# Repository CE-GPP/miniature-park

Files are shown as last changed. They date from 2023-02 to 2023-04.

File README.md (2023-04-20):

# QEOP Data Dashboard Device

###### Dongyoung Lim, Jingqi Cheng, Patrick Whyte, Yining An
---
<p align="center">
Device
</p>

The QEOP Data Dashboard Device is a real-time, aesthetically pleasing data dashboard designed to provide users with comprehensive information about the Queen Elizabeth Olympic Park (QEOP) and its surrounding environment. The device combines the functionality of a data dashboard with the visual appeal of an objet d'art, making it accessible and engaging for general users.

<p align="center">
Controlling Device
</p>

## Features
- Real-time data visualisation
- Intuitive user experience with geographical context
- High-quality, visually appealing design
- Customisable map layers
- Interactive map with weather, network coverage, 3D buildings, and more

## Getting Started
1. Clone the repository.
```
git clone https://github.com/CE-GPP/miniature-park.git
```
2. Run the device control application.
```
cd device/controls
python main.py
```
3. Navigate to the project directory.
```
cd ../../
cd map/weatherleaflet
```
4. Install the required dependencies.
```
npm install
```
5. Run the backend application.
```
node app.js
```
6. Run the frontend application.
```
cd demo
npx live-server
```

## Tech Stack
### Map Application
- JavaScript
- Leaflet
- Node.js
- Express.js
- Socket.io
- MQTT.js

### Device Control
- Python
- Adafruit GFX Library
- Adafruit-ST7735-Library

### Device Components
- Raspberry Pi 4 Model B
- Elecrow RC070LCD Display with Touch Screen
- Adafruit 1.9" 320x170 Color IPS TFT Display
- EC11 Rotary Encoder Module

> Bill of Materials : https://github.com/CE-GPP/miniature-park/blob/main/report/src/Sketch_bom.png

## Project Structure
- `device/controls` : Contains code for the sub-display and the rotary encoder.
- `device/device model` : Contains 3d model of enclosure.
- `device/fabrication` : Contains drawings of the enclosure for fabrication.
- `device/map`: Contains 3d model of QEOP map for the 3d printing.
- `map/weatherleaflet` : Contains map application including the frontend and backend.

## Application architecture

<p align="center">
Application architecture
</p>

## Development procedures
- Design and development of a transparent 3D printed model in Blender.
- Creation of a wooden enclosure using laser cutting and wood stain to achieve a classic oak appearance.
- Integration of a 7-inch main display with HDMI support, a 1.9-inch sub-display with a custom UI for a dynamic data feed, and an EC11 rotary encoder for easy control.
- Utilisation of a Raspberry Pi 4 for computing and displaying data, allowing for quick software development using Python and web-based frameworks.

<p align="center">
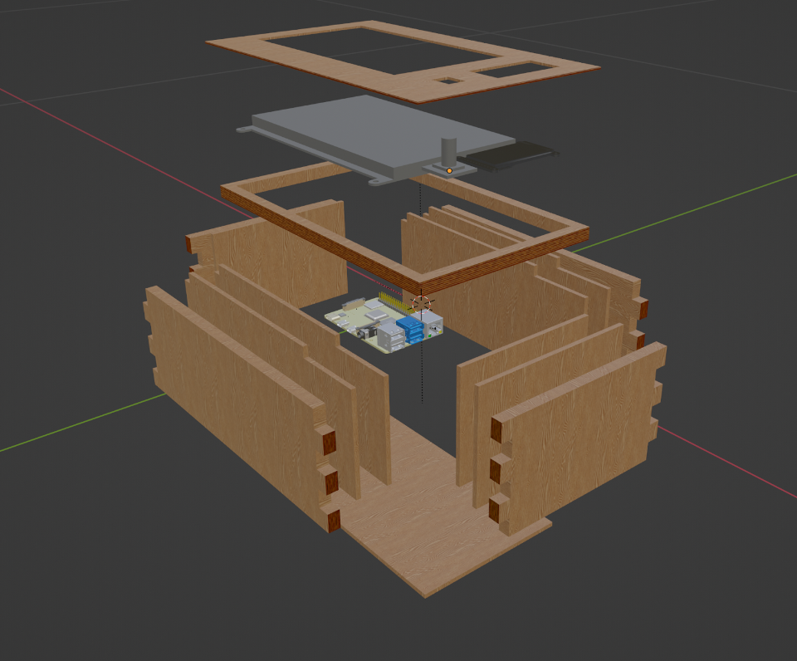
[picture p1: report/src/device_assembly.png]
Device Assembly

</p>

## Contributing
We welcome contributions from the community. If you'd like to contribute to the QEOP Data Dashboard Device, please follow these steps:

1. Fork the repository
2. Create a new branch with a descriptive name, e.g., feature/new-map-layer
3. Commit your changes to the new branch
4. Submit a pull request to the main repository

Please make sure your code follows the existing style guidelines and provide a detailed description of your changes in the pull request.

<p align="center">
Device
</p>

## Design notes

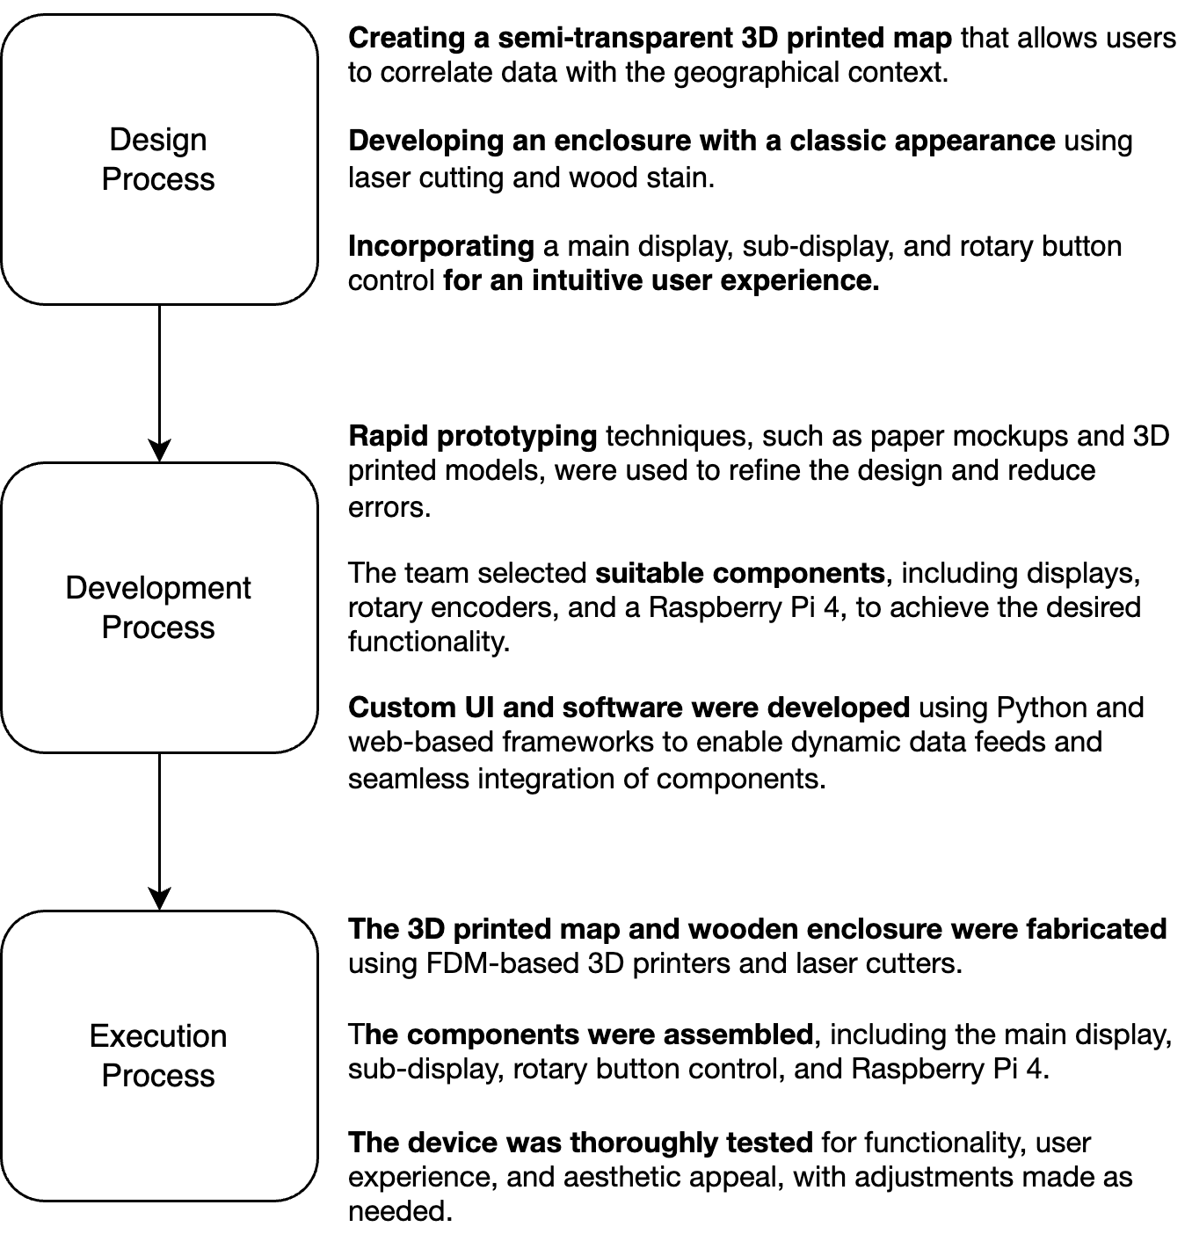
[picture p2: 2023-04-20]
report/src/Development Process.png

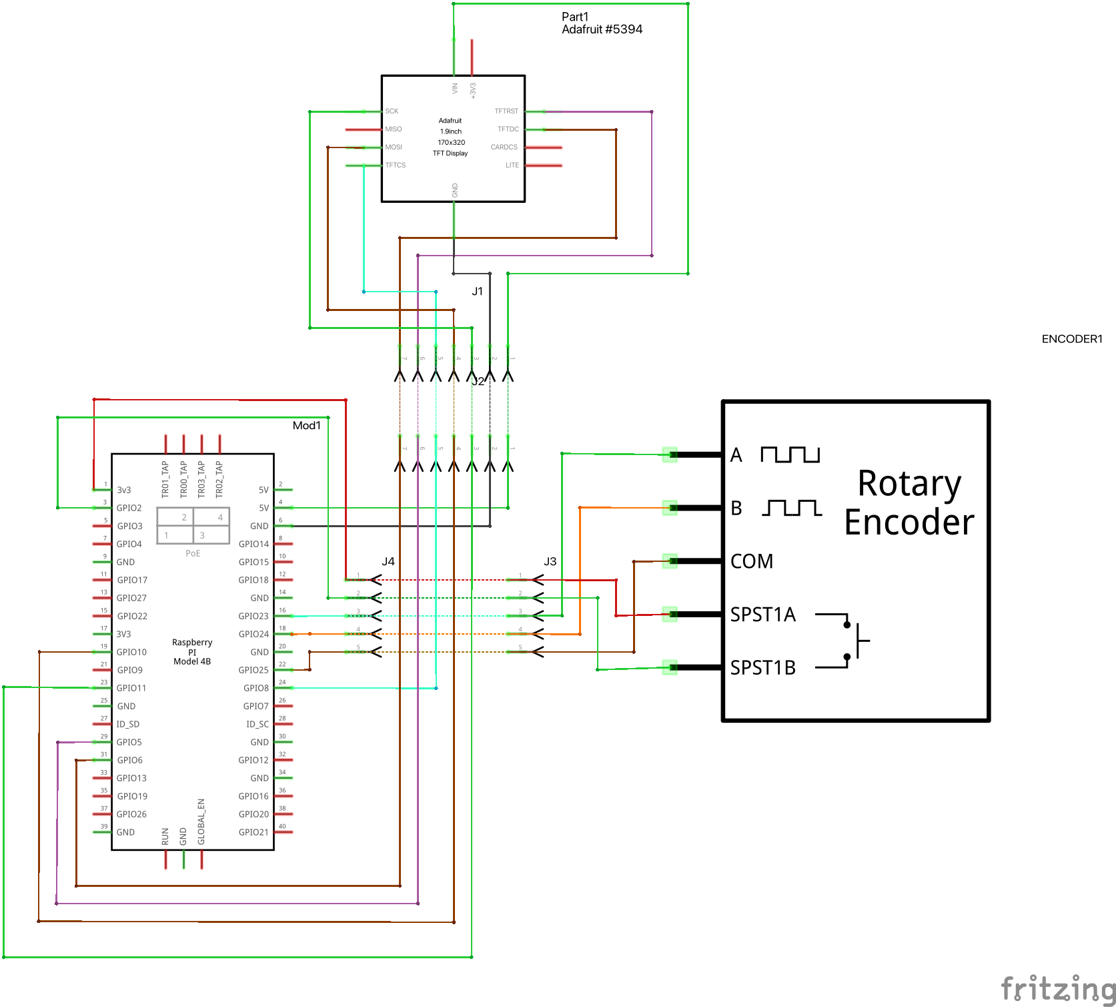
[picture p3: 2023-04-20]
report/src/Sketch_schem.png

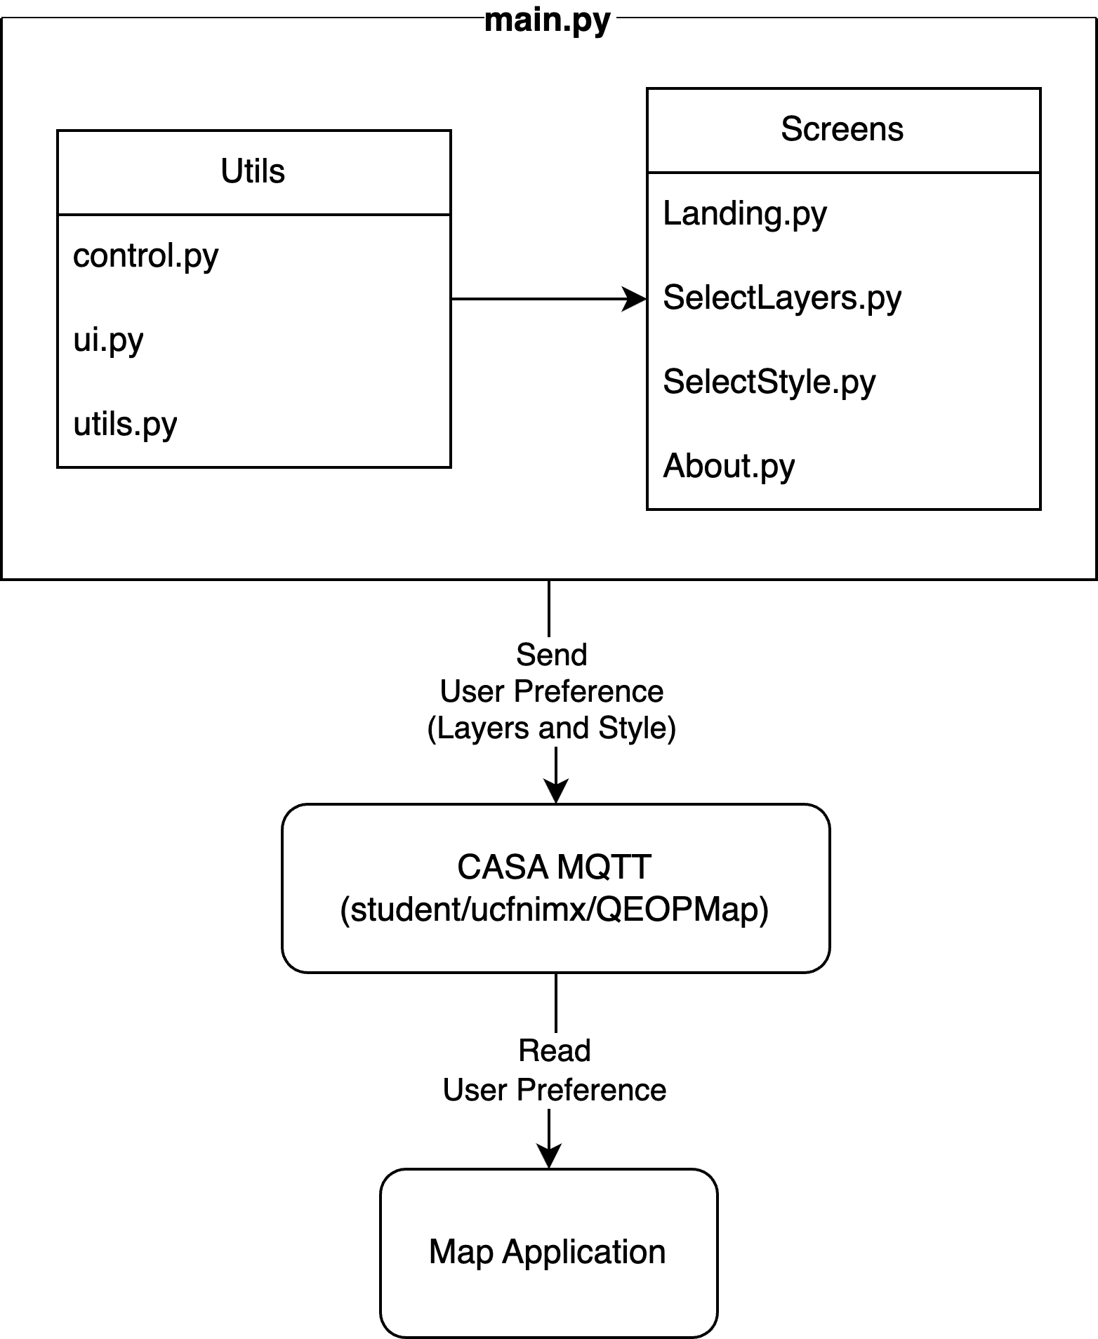
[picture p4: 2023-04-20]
report/src/UI.png

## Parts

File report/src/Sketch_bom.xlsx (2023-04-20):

Bill of Materials
Assembly List
Label | Part Type | Properties | Price | Link
ENCODER1 | EC11 Rotary Encoder Module | Module Size: 33.8 * 22.4 (mm) /1.3 * 1.1 (inches) | £3.00 | https://shop.pimoroni.com/products/ec11-rotary-encoder-module
J1 | Generic female header - 7 pins | package THT; pins 7; hole size 1.0mm,0.508mm; row single; pin spacing 0.1in (2.54mm); form ♀ (female) | £2.00 | https://shop.pimoroni.com/products/female-headers
J2 | Generic female header - 7 pins | package THT; pins 7; hole size 1.0mm,0.508mm; row single; pin spacing 0.1in (2.54mm); form ♀ (female)
J3 | Generic female header - 5 pins | package THT; pins 5; hole size 1.0mm,0.508mm; row single; pin spacing 0.1in (2.54mm); form ♀ (female)
J4 | Generic female header - 5 pins | package THT; pins 5; hole size 1.0mm,0.508mm; row single; pin spacing 0.1in (2.54mm); form ♀ (female)
Mod1 | Raspberry Pi 4B | processor Broadcom 2711, Quad-core Cortex-A72 64-bit SoC @ 1.5GHz; variant Raspberry Pi 4B | £62.40 | https://shop.pimoroni.com/products/raspberry-pi-4?variant=29157087445075
Part1 | Adafruit 1.9in 320x170 TFT | variant variant 1; part # Adafruit #5394 | £17.10 | https://shop.pimoroni.com/products/adafruit-1-9-320x170-color-ips-tft-display-st7789
 | Elecrow RC070LCD Display with Touch Screen | 7 Inch 1024*600 HDMI | £50.00 | https://www.amazon.co.uk/gp/product/B076J8ZWFF
 |  | Total | £134.50
Enclosure
Label | Part Name | Size | Price | Link
 | Plywood - 3mm | 600mm x 300mm | £4.00 | https://www.amazon.co.uk/Trustleaf-300x600mm-Plywood-Sheets-SECONDS/
 | Plywood - 8mm | 600mm x 300mm | £12.45 | https://www.amazon.co.uk/Birch-Plywood-making-furniture-300mm/
 | Furniture Clinic Wood Stain | 250 ml | £9.45 | https://www.amazon.co.uk/Furniture-Clinic-Stain-250ml-Mahogany/
 |  | Total | £25.90
 |  | Grand Total | £160.40

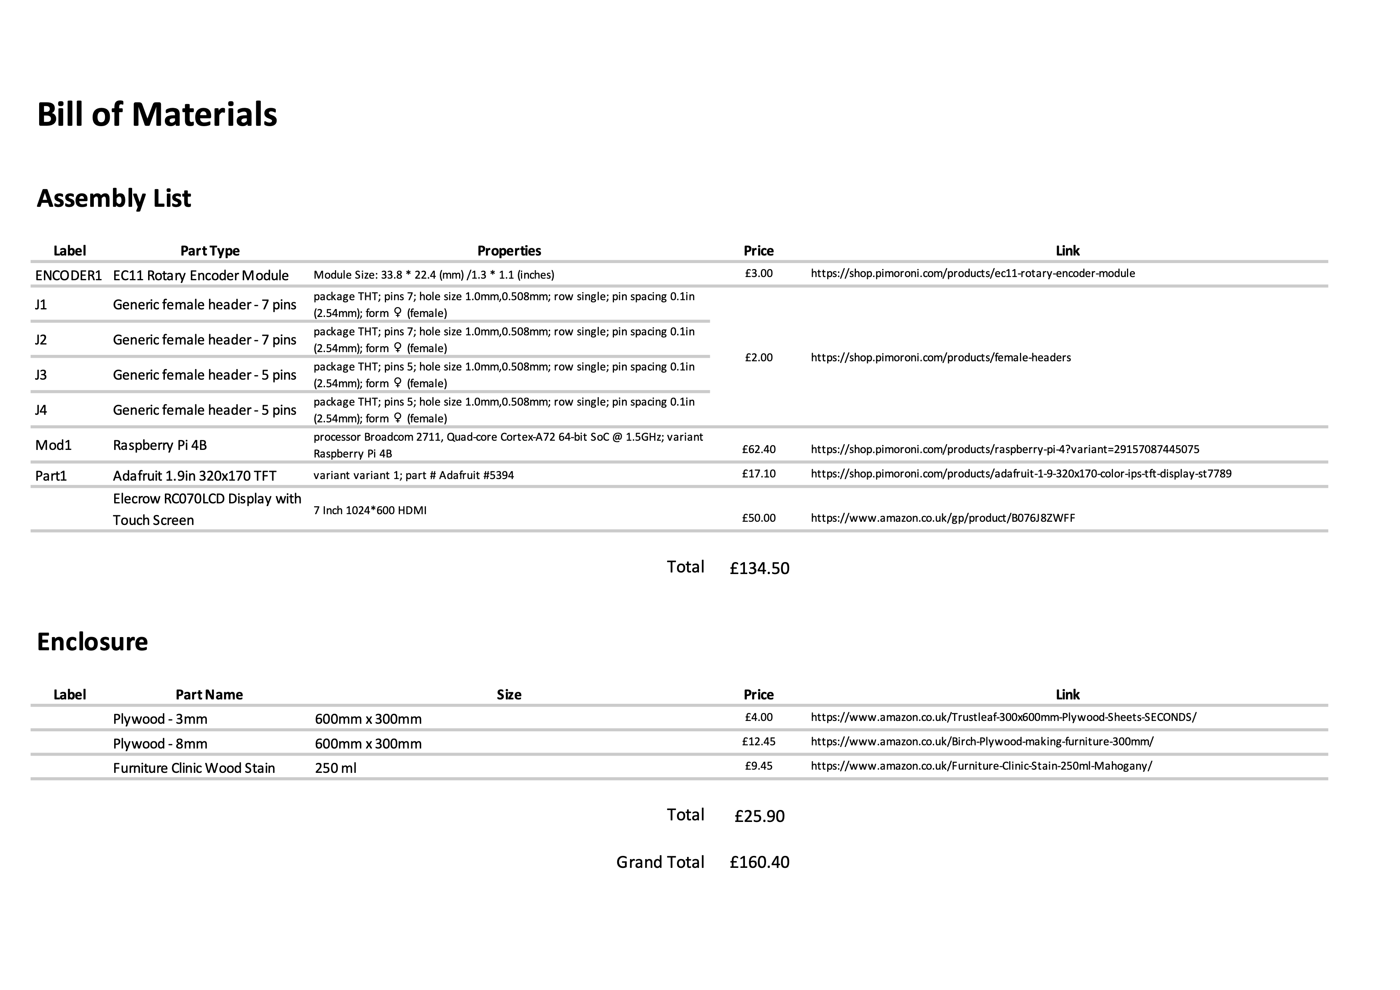
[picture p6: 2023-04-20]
report/src/Sketch_bom.png

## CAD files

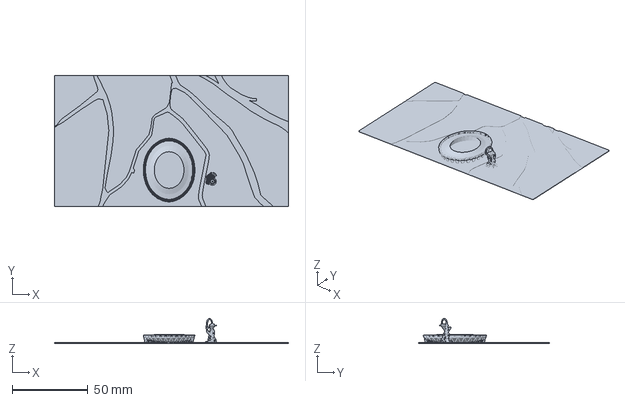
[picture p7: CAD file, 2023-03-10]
device/map/UMS5_QEOP_Scaled_test.3mf
154.0 x 86.0 x 16.7 mm

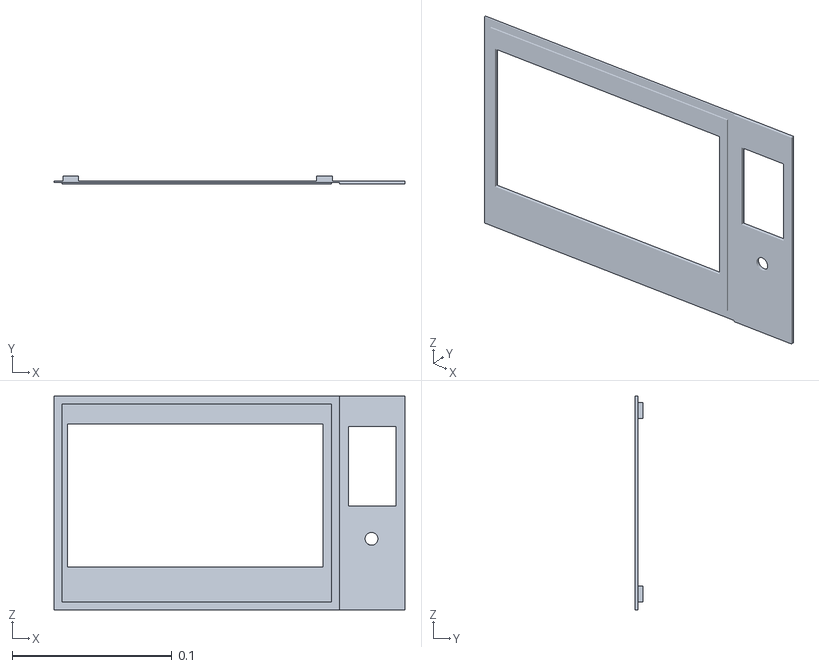
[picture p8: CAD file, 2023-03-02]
device/prototype models/holder2.stl
0.22 x 0.005 x 0.134

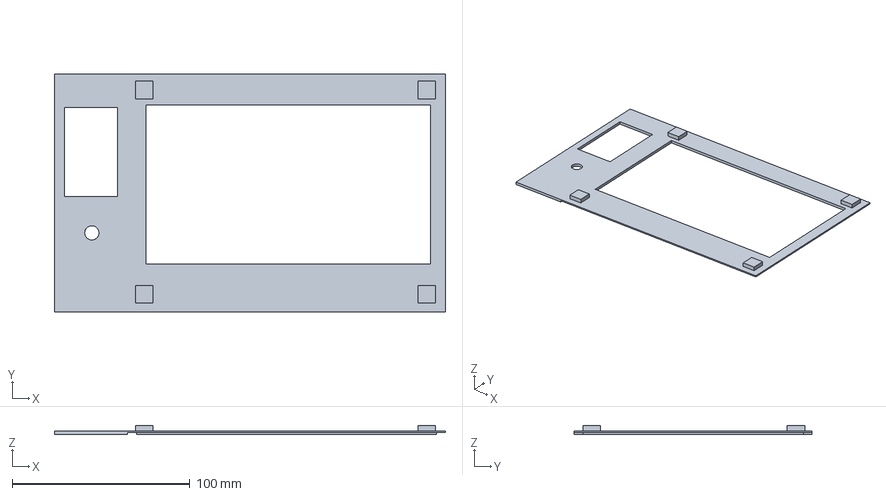
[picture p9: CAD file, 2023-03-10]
device/prototype models/prusa/holder2_v2.3mf
220.0 x 134.0 x 5.00 mm

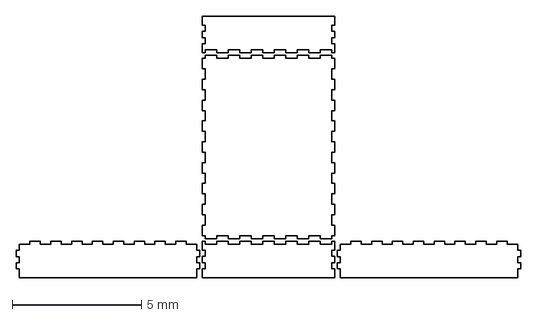
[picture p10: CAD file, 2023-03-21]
device/fabrication/cover_dxf.dxf
19.5 x 10.1 mm

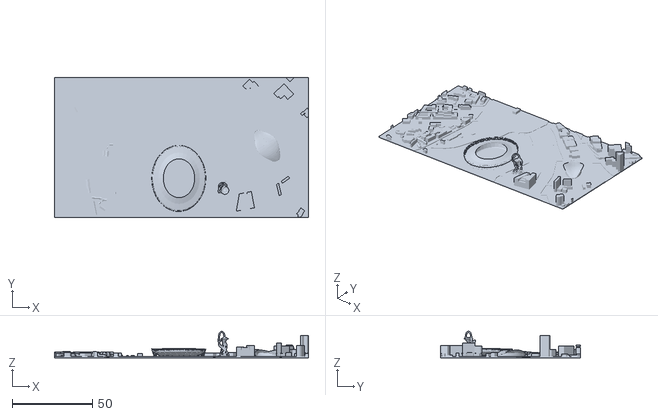
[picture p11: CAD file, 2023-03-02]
device/map/QEOP_v2.stl
158.0 x 87.0 x 16.7

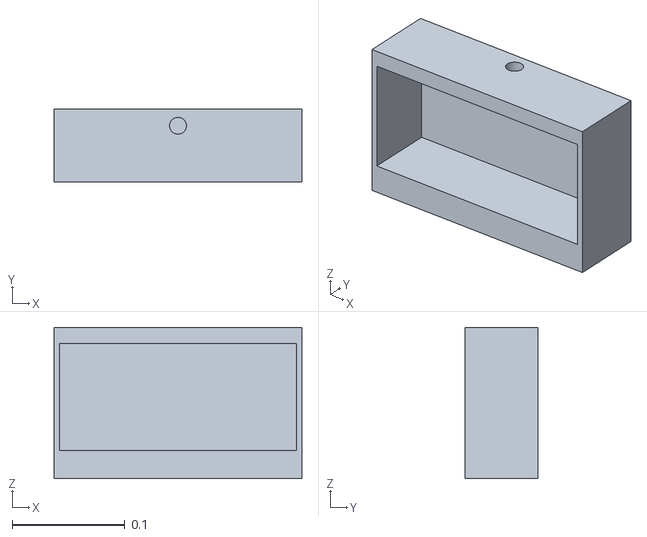
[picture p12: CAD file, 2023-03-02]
device/prototype models/container_V2.stl
0.22 x 0.065 x 0.134

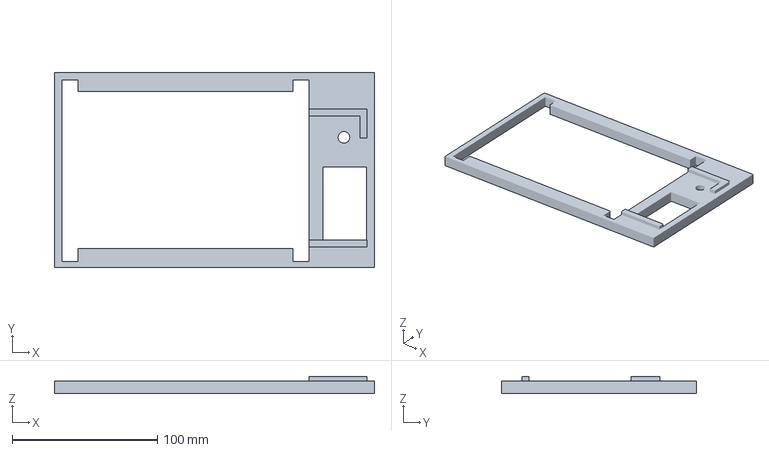
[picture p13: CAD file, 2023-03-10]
device/prototype models/prusa/holder1_v2.3mf
220.0 x 134.0 x 11.8 mm

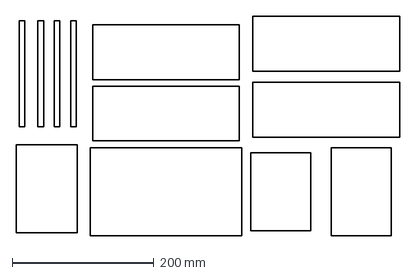
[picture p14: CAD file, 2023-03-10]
device/fabrication/3.5.dxf
540.5 x 309.3 mm

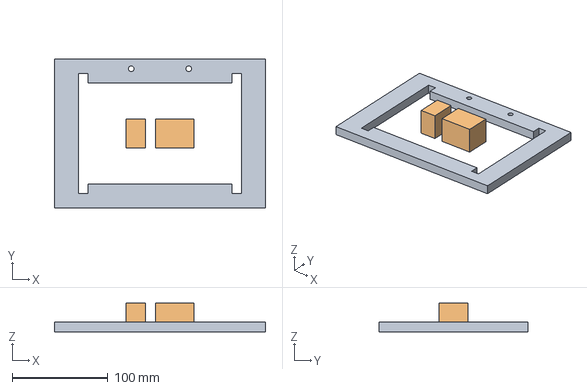
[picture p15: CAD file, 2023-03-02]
device/prototype models/prusa/support.3mf
220.0 x 155.0 x 30.0 mm
holder1.stl
support.stl

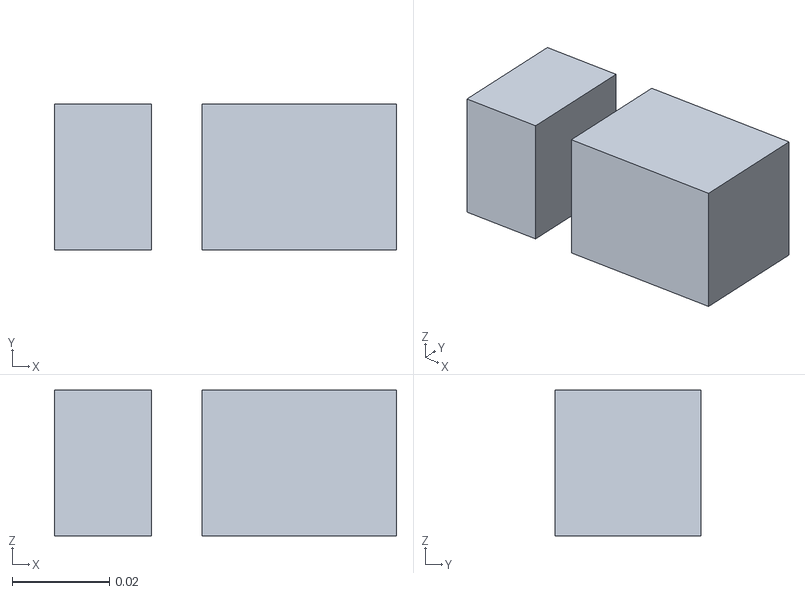
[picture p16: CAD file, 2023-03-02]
device/prototype models/support.stl
0.0704 x 0.03 x 0.03

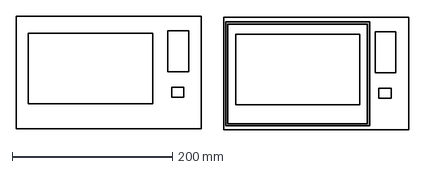
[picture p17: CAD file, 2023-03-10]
device/fabrication/1.5.dxf
489.9 x 142.2 mm

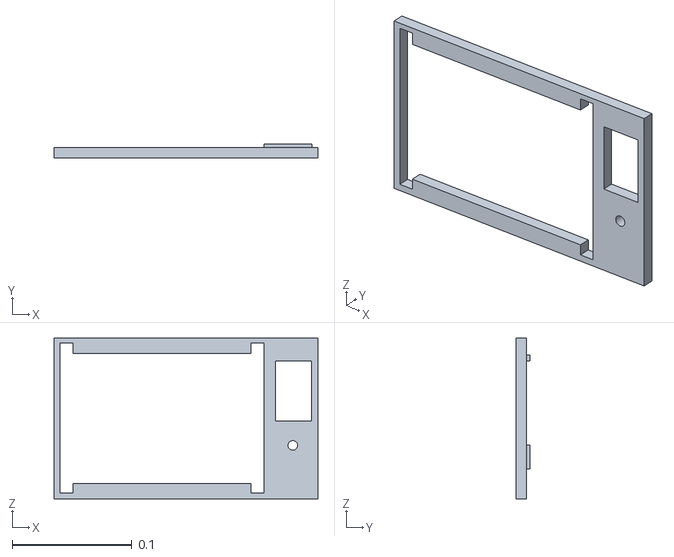
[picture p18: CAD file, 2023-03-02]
device/prototype models/holder1.stl
0.22 x 0.0118 x 0.134

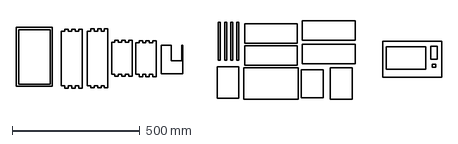
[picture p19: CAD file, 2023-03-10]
device/fabrication/production.dxf
1665.5 x 309.3 mm

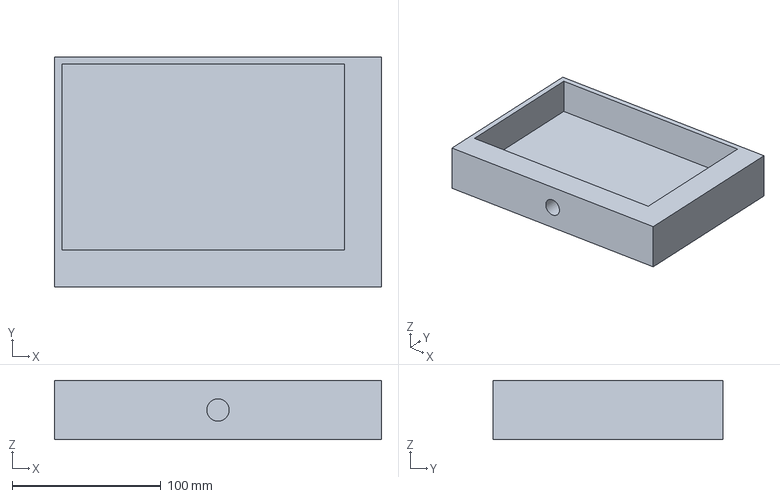
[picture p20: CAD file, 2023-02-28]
device/prototype models/prusa/container.3mf
220.0 x 155.0 x 40.0 mm

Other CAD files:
device/fabrication/cover.dwg
device/fabrication/8.5.dxf
device/prototype models/prusa/holder2.3mf
device/prototype models/container.stl
device/fabrication/1.5.dwg
device/fabrication/3.5.dwg
device/fabrication/8.5.dwg
device/fabrication/production.dwg
device/prototype models/3dPrintConfigModel.blend

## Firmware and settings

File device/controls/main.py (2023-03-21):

import sys
sys.path.append('/home/DYpi/QEOP/screens')
sys.path.append('/home/DYpi/QEOP/utils')
import board
import displayio
import utils as utils
import SelectLayers as SelectLayers
import SelectStyle as SelectStyle
import Landing as Landing
import About as About
from adafruit_st7789 import ST7789

spi = board.SPI()
tft_cs = board.D8
tft_rst = board.D5
tft_dc = board.D6

baseLayers = {'Satellite' : 'Satellite', 
              'GreyCanvas' : 'Grey'
              }
overLayers= {
    'Weather' : 'weather', 
    'Network':'heatmapLayer', 
    '3D':'osmb', 
    'Shadow':'shadeMap', 
    'Bycycle':'markerLayer',
    'Wind':"Wind"
    }

menu = ['Layers','Style','About']

# Release any resources currently in use for the displays
displayio.release_displays()
display_bus = displayio.FourWire(spi, command=tft_dc, chip_select=tft_cs, reset=tft_rst)
display = ST7789(display_bus, width=170, height=320, colstart=35, rotation=0, brightness = 1, backlight_pin = board.D13)


while True:
    landingPage = Landing.LandingScreen(display, displayio, menu)
    menuIndex = landingPage.runScreen()
    if menuIndex == 0:
        selectLayersScreen = SelectLayers.SelectLayers(display, displayio, overLayers)
        print(selectLayersScreen.runScreen())
    elif menuIndex == 1:
        selectStyleScreen = SelectStyle.SelectStyle(display, displayio, baseLayers)
        print(selectStyleScreen.runScreen())
    elif menuIndex == 2:
        aboutScreen = About.AboutScreen(display, displayio)
        aboutScreen.runScreen()
    else:
        print(menuIndex)
# selectLayersScreen = SelectLayers.SelectLayers(display, displayio, layers)
# print(selectLayersScreen.runScreen())

# display_bus.reset()

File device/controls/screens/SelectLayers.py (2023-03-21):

import sys
sys.path.append('/home/DYpi/QEOP/utils')
import time
import RPi.GPIO as GPIO
import json
import utils as utils
import ui as ui
import colors as colors

FOCUS = 0
SECRETE_ADDRESS = 'QEOP/secrete.txt'

encoderPinA = 23
encoderPinB = 24
buttonPin = 25

encoderValue = 0
previousValue = 0
lastEncoded = 0


def update_encoder(channel):
    global encoderValue, lastEncoded
    MSB = GPIO.input(encoderPinA)
    LSB = GPIO.input(encoderPinB)

    encoded = (MSB << 1) | LSB
    sum = (lastEncoded << 2) | encoded

    if sum == 0b1101 or sum == 0b0100 or sum == 0b0010 or sum == 0b1011:
        encoderValue += 1
    if sum == 0b1110 or sum == 0b0111 or sum == 0b0001 or sum == 0b1000:
        encoderValue -= 1

    lastEncoded = encoded

def moveFocus(direction, layers):
    global FOCUS
    itemNumber = len(layers)
    if direction == True:
        FOCUS = FOCUS + 1 if FOCUS + 1 < itemNumber else 0
    else:
        FOCUS = itemNumber - 1 if FOCUS - 1 < 0 else FOCUS - 1

def read_encoder_value(layers):
    global encoderValue, previousValue
    value = encoderValue // 4
    change = (value - previousValue)
    if change > 0:
        moveFocus(True, layers)
    elif change < 0:
        moveFocus(False, layers)
    previousValue = value
    return value

def is_button_push_down():
    debounce_time = 50  # set the debounce time in milliseconds
    if not GPIO.input(buttonPin):
        time.sleep(debounce_time/1000.0)  # wait for the debounce time
        if not GPIO.input(buttonPin):
            return True
    return False

class SelectLayers:
    def __init__(self, display, diaply_io, layers):
        self.display = display
        self.displayio = diaply_io
        self.menu = self.displayio.Group()
        self.layers = layers
        self.colour = colors.Colors()

        try:
            GPIO.setmode(GPIO.BCM)

            GPIO.setup(encoderPinA, GPIO.IN, pull_up_down=GPIO.PUD_UP)
            GPIO.setup(encoderPinB, GPIO.IN, pull_up_down=GPIO.PUD_UP)
            GPIO.setup(buttonPin, GPIO.IN, pull_up_down=GPIO.PUD_UP)

            GPIO.add_event_detect(encoderPinA, GPIO.BOTH, callback=update_encoder)
            GPIO.add_event_detect(encoderPinB, GPIO.BOTH, callback=update_encoder)
        except:
            GPIO.cleanup()
            print("Set Up Connection Failed.")

    def runScreen(self):
        global FOCUS
        layersDict = self.layers
        displayLayer = list(layersDict.keys())
        valueLayer = list(layersDict.values())

        displayLayer.append('Finish')
        
        selectedLayers = {layers: False for layers in displayLayer}

        self.uiGen = ui.Generator(self.display, self.displayio)

        self.display.show(self.menu)
        
        self.menu.append(self.uiGen.focusBox(displayLayer, 0))
        # Draw a smaller inner rectangle
        for box in self.uiGen.drawBoxes(displayLayer):
            self.menu.append(box)

        while True:
            value = read_encoder_value(displayLayer)
            self.menu[0] = self.uiGen.focusBox(displayLayer, FOCUS)
            if is_button_push_down():
                boxIndex = (FOCUS * 2) + 1
                if FOCUS == len(displayLayer) - 1:
                    selectedLayers.popitem()
                    selectedLayers = {valueLayer[i]: list(selectedLayers.values())[i] for i in range(len(selectedLayers))}
                    json_str = json.dumps(selectedLayers)
                    with open(SECRETE_ADDRESS, "r") as f:
                        result = utils.publishMQTT('mqtt.cetools.org',
                                        1884,
                                        'student',
                                        f.read().strip(),
                                        "student/ucfnimx/QEOPMap/layer",
                                        json_str
                                        )
                    GPIO.remove_event_detect(encoderPinA)
                    GPIO.remove_event_detect(encoderPinB)
                    print(json_str)
                    return result.is_published()
                elif selectedLayers[displayLayer[FOCUS]] == True:
                    selectedLayers[displayLayer[FOCUS]] = False
                    self.menu._layers[boxIndex].pixel_shader._colors[0]['rgba'] = utils.hexToRGBA(self.colour.NORMAL_COLOUR)
                else:
                    selectedLayers[displayLayer[FOCUS]] = True
                    self.menu._layers[boxIndex].pixel_shader._colors[0]['rgba'] = utils.hexToRGBA(self.colour.SELECTED_COLOUR)

            time.sleep(0.1)
            pass

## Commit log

2023-02-28 3d print prototyping models
    [container.3mf, container.stl, holder1.stl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]
2023-03-02 updated version2 enclosure
    [3dPrintConfigModel.blend, QEOP_v2.stl, container_V2.stl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]
2023-03-10 updated enclosure drawings
    [1.5.dwg, 1.5.dxf, 3.5.dwg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]
2023-03-16 added controlling codes
    [production.dwg]
2023-03-17 Add files via upload
    Receive button return from MQTT, and pass it to javascript web
2023-03-21 Revert "updated component control codes"
    This reverts commit 1307d56ae2ef2fdeb2fa5f246d1ae4c54914b3ed.
    [About.py, Landing.py, SelectLayers.py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]
2023-03-21 updated component controlling code
    [cover.dwg, cover_dxf.dxf]
2023-04-20 upload the resources for the report
    [Sketch.fzz, Sketch_bom.xlsx]
2023-04-20 removed unnecessary files
    [1.5.dwg, 1.5.dxf, 3.5.dwg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]
2023-04-20 upload report materials
2023-04-20 upload report material
